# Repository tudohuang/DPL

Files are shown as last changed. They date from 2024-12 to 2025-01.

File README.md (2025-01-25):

# TISF 4th Prize!!!!!!

[URL](https://www.z-gtech.com.tw/TISF2025/100040.html)
# Digital Physics Laboratory Project Manual

## 1. Introduction
The Digital Physics Laboratory Project leverages millimeter-wave radar technology to enable precise, non-contact motion measurement for physics experiments. This manual serves as a comprehensive guide to understanding, replicating, and utilizing the system effectively, with a focus on making it accessible for educators and students.
This project is tailored to empower educators in creating engaging, hands-on experiences for students, bridging theoretical concepts with practical applications. Whether you are a teacher introducing basic mechanics or an advanced student exploring signal processing, this system provides a versatile platform to enhance learning.

## 2. System Overview

### Core Components

1. **Millimeter-Wave Radar**:
    - **Model**: RFbeam Microwave GmbH K-LC7
    - **Operating Frequency**: $f_t = 24GHz$
    - **Function**: Captures motion data and outputs analog signals, which are processed to derive velocity and displacement.
    - **Key Features**:
        - Compact design for easy integration.
        - High sensitivity for small motion detection.
    - **Applications**: Non-contact motion tracking, vibration analysis, and frequency measurement.

2. **Signal Conditioning Circuit**:
    - **Purpose**: Amplifies and filters radar output signals to ensure compatibility with the ADC in the ESP32 microcontroller.
    - **Design**:
        - Low-noise amplifier (LNA) using OPA4340 for signal amplification.
        - Band-pass filter to isolate desired frequency ranges.
    - **Software Tools**:
        - Designed using KiCad for schematics and PCB layout.
    - **Physical Details**:
        - Total PCB size: $\approx 500mm^2$
        - Compact design allows easy integration into enclosures.
    - **Applications**:
        - Noise reduction in signal acquisition.
        - Improved ADC accuracy and signal stability.

3. **ESP32 Microcontroller**:
    - **Purpose**: Converts conditioned analog signals to digital data and transmits them to a computer via a serial port for analysis.
    - **Key Features**:
        - 12-bit ADC resolution for high-accuracy digitization.
        - Real-time data processing capabilities.
    - **Software Support**:
        - Programmed using Arduino IDE for easy development and deployment.
    - **Connections**:
        - Analog input: Receives conditioned signals from the radar.
        - Serial output: Sends digital data to a connected PC or device.
    - **Applications**:
        - Real-time motion analysis.

4. **Python-Based Software**:
    - **Purpose**: Processes and visualizes the collected data from the ESP32.
    - **Key Features**:
        - **Signal Processing**:
            - High-pass filtering to remove low-frequency noise.
            - FFT (Fast Fourier Transform) for frequency domain analysis.
        - **Visualization**:
            - Time-domain plots for raw and filtered signals.
            - Frequency spectrum analysis for identifying dominant frequencies.
        - **Customization**:
            - Open-source Python scripts allow users to modify and expand functionality.
    - **User Interface**:
        - Provides a command-line interface (CLI) for loading and analyzing data.
        - Optional GUI for real-time visualization (developed using Tkinter).
    - **Applications**:
        - Understanding harmonic motion and resonance.

## 3. Hardware Guide

### Schematics
- The schematic (`design_project.pdf`) provides a detailed blueprint of the system. It includes:
  1. **Radar Module**: Interfaces with the 24 GHz radar.
  2. **Amplification Stage**: Features OPA4340 for low-noise signal conditioning.
  3. **Microcontroller Connections**: Configures ADC inputs and communication lines.
  4. **Power Management**: Converts 5V to 3.3V using AMS1117.

### PCB Design
- **Gerber Files**: Located in the `hardware/PCB/` folder, ready for PCB fabrication.
- **3D Model**: Available in `hardware/3D_model/` for visualization and enclosure design.
- **Assembly Notes**:
  1. Solder components carefully to avoid thermal damage.
  2. Use decoupling capacitors to stabilize power supply lines.

## 4. Firmware Guide

### Overview
The firmware is designed for the ESP32 microcontroller and performs:
1. **ADC Sampling**: Converts analog radar signals to digital data.
2. **Data Transmission**: Sends data wirelessly for analysis.

### File Structure
- `adc_sampling.cpp`: Initializes and manages ADC sampling.
- `esp32_config.cpp`: Sets up ESP32 peripherals.
- `main.ino`: Main entry point for the program.

### Deployment
1. Open the firmware folder in Arduino IDE.
2. Connect the ESP32 to your computer.
3. Select the appropriate board and port.
4. Upload the code to the ESP32.

---

## 5. Software Guide

### Python-Based Analysis
- The software is located in the `software/` folder.
- Required dependencies are listed in `requirements.txt`.
- Key scripts:
  1. `gui.py`: Provides a graphical interface for real-time analysis.
  2. `data_collector.py`: Handles data acquisition and preprocessing.

### Running the Software
1. Install dependencies:
   ```bash
   pip install -r requirements.txt
   ```
2. Execute the analysis script:
   ```bash
   python gui.py
   ```

---

## 6. Examples and Usage

### Example Data
- Sample datasets are provided in the `examples/` folder:
  - `spring_oscillation_20g.csv`: Data for 20g mass.
  - `spring_oscillation_40g.csv`: Data for 40g mass.

### Visualization
- Run the example analysis script:
  ```bash
  python analyze_example.py --input_file spring_oscillation_20g.csv
  ```
- Output includes:
  1. Frequency spectrum visualization.
  2. Filtered motion data.

### Teacher Notes
- Encourage students to hypothesize the effects of varying mass on oscillation frequency.
- Demonstrate how data filtering improves signal clarity and measurement accuracy.
- Use provided Python scripts as a stepping stone for students to develop their own data analysis tools.

---

## 7. Educational Applications

### Enhancing Physics Labs
This system introduces students to cutting-edge measurement techniques, bridging traditional physics experiments with modern technology:
- **Harmonic Motion Experiments**:
  - Measure oscillation frequencies of different masses.
  - Analyze how the spring constant and damping factors affect motion.
- **Waveform Analysis**:
  - Teach students about filtering and noise reduction.
  - Visualize motion data in real-time.

### Data Literacy
- **Data Collection**:
  - Show students how to collect accurate, repeatable measurements using radar and microcontrollers.
- **Data Analysis**:
  - Use Python scripts to process data, introducing students to concepts like FFT (Fast Fourier Transform) and time-domain analysis.

### Cross-Disciplinary Applications
This system provides opportunities for collaboration between physics, electronics, and computer science courses:
- **Physics**: Understanding motion and forces.
- **Electronics**: Building and testing circuits.
- **Programming**: Writing and modifying analysis scripts.

### Accessibility
- Open-source design ensures that schools with limited budgets can implement advanced measurement systems at a fraction of the cost of commercial solutions.
- Modular design allows educators to adapt the system for various experiments, from pendulum studies to resonance analysis.

### Inspiring Creativity
- Encourage students to explore beyond harmonic motion by experimenting with non-linear systems, compound pendulums, or even chaotic oscillators.
- Allow students to modify the firmware or analysis scripts to fit specific experimental needs.

---

## 8. Appendix

### Bill of Materials (BOM)
Refer to `hardware/bill_of_materials.csv` for a complete list of components, including:
- Resistors, capacitors, and ICs.
- Radar module and ESP32 board.

### FAQ
**Q**: What should I do if the radar output is noisy?
**A**: Ensure proper grounding and use shielded cables.

**Q**: How can I modify the filter parameters?
**A**: Edit the cutoff frequency and order in the firmware.

**Q**: Can this system be used for other types of motion analysis?
**A**: Yes, the modular design allows for various applications, including pendulums, resonance experiments, and fluid dynamics visualization.

### Example Output
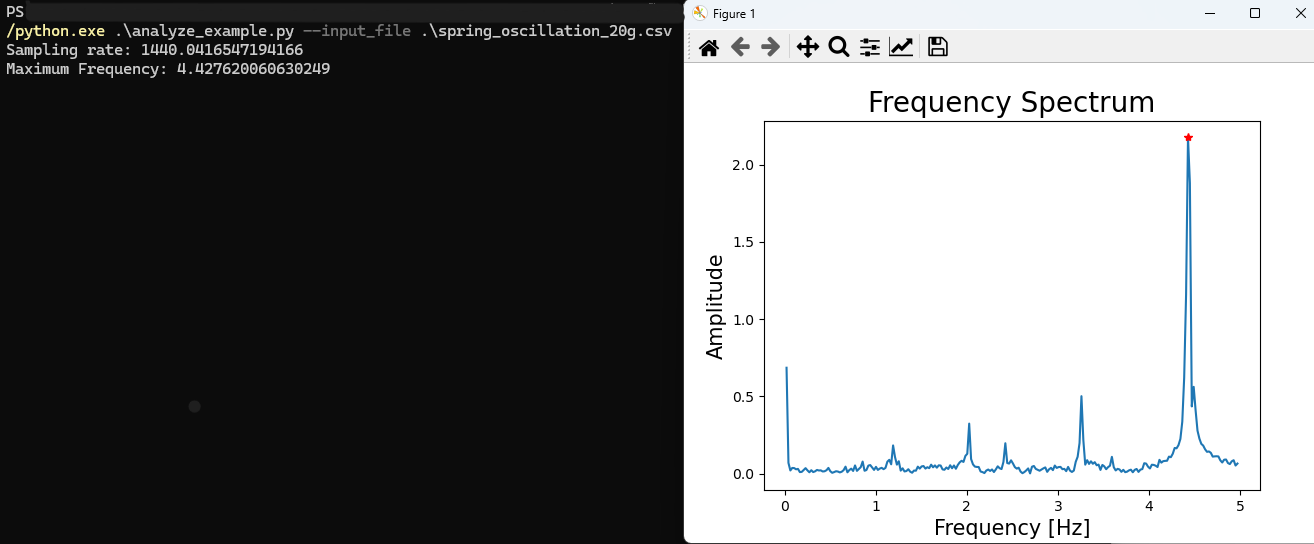
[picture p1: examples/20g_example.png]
Example Output

- Frequency spectrum of 20g mass oscillation.

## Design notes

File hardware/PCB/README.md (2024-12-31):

# PCB Design

This folder contains the Gerber files for manufacturing the PCB of the Digital Physics Laboratory project. These files are ready for direct submission to a PCB fabrication service.

## Files
- `design_project_top.gtl`: Top copper layer.
- `design_project_bottom.gbl`: Bottom copper layer.
- `design_project.gko`: PCB outline layer.
- `design_project_drills.xln`: Drill file for vias and holes.

## How to Use
1. Submit these files to a PCB manufacturer (e.g., JLCPCB, PCBWay).
2. Specify the board thickness and finish type as per your requirements.
3. Verify the design using a Gerber viewer before submission.

## Notes
- The PCB includes isolation between analog and digital sections to minimize noise.
- Ensure you procure components as per the Bill of Materials (BOM) for assembly.

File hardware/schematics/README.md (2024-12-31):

# Schematics

This folder contains the schematic for the Digital Physics Laboratory project in PDF format. The original editable schematic files are not included to ensure simplicity and compatibility.

## Files
- `design_project.pdf`: A complete schematic in PDF format for quick reference.

## How to Use
1. Open the `design_project.pdf` file in any PDF viewer.
2. Refer to the annotations in the schematic for component values and connections.

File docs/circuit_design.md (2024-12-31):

# Circuit Design

## Overview
The circuit design integrates a 24 GHz millimeter-wave radar module with a custom PCB, enabling precise and real-time motion measurement. The system is divided into three main parts:
1. **Analog Frontend**: Filters and amplifies radar signals.
2. **Microcontroller Unit (MCU)**: Converts analog signals to digital and transmits data.
3. **Power Supply**: Provides stable and regulated voltage for all components.

## Objectives
- Ensure low noise and high signal integrity.
- Optimize PCB layout for minimal interference.
- Enable compatibility with standard educational lab setups.

---

## System Architecture
The system architecture is divided into functional blocks:

### **1. Radar Module**
- **Component**: K-LC7 24 GHz Doppler Radar
- **Features**:
  - Transmits and receives radar signals.
  - Outputs raw analog signals proportional to motion.

### **2. Signal Conditioning**
- **Purpose**: Enhance radar output signals for ADC compatibility.
- **Components**:
  - **Operational Amplifier**: OPA4340 (Low noise, high precision), 4 OP included.
  - **Filters**:
    - **Bandpass Filter**: 4 Hz to 1 kHz to eliminate noise and unwanted frequencies.
    - **Low-pass Filter**: Attenuates high-frequency noise.
- **Implementation**:
  - Two-stage amplification with adjustable gain.

### **3. Microcontroller**
- **Component**: ESP32 Dev Module
- **Features**:
  - Built-in 12-bit ADC for analog-to-digital conversion.
  - Wi-Fi for wireless data transmission.
- **Firmware**:
  - Configures ADC for precise sampling.
  - Implements signal processing algorithms.

### **4. Power Supply**
- **Components**:
  - **Regulator**: AMS1117 (5V to 3.3V conversion).
  - **Decoupling Capacitors**: Reduces power supply noise.
- **Features**:
  - Ensures stable power for radar, MCU, and signal conditioning circuits.

---

## PCB Design
### **Software**
- Designed using **KiCad**:
  - Custom symbol and footprint libraries.
  - Layered PCB layout for signal integrity.

### **Layout**
- **Size**: 100 mm x 50 mm.
- **Layers**:
  - **Top Layer**: Analog and digital components.
  - **Bottom Layer**: Ground plane and power routing.
- **Highlights**:
  - Analog and digital sections are isolated to reduce interference.
  - Multiple vias for effective grounding.

---

## Schematic and PCB Files
- The complete schematic and PCB files are available in the `hardware/` folder:
  - `hardware/schematics/radar_module.sch`
  - `hardware/pcb/radar_module.kicad_pcb`

---

## Challenges and Solutions
### **Challenge**: High-frequency noise from radar output.
- **Solution**: Implemented multi-stage filtering and grounding techniques.

### **Challenge**: PCB space constraints.
- **Solution**: Used SMD components and optimized layout.

---

## Key Features
- Modular design allows easy upgrades.
- Low-cost components for educational accessibility.
- Open-source design to encourage replication and improvement.

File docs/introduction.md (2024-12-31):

# Introduction

## Abstract

Our study aims to design and apply a digital physics experimental system based on millimeter-wave radar, specifically for the precise quantification of spring harmonic motion. Traditional physics experiments are often limited by errors from manual measurements and visual observation, but this system uses a 24 GHz millimeter-wave radar combined with a custom-designed circuit board for real-time, non-contact motion measurement.

By designing the printed circuit board, writing firmware to convert analog signals into digital data, and using Python for data analysis, the system successfully measured the effects of different masses on the spring's oscillation frequency. The experimental results showed that after accounting for the spring's own mass, the root mean square error between the measured data and theoretical values decreased from 0.62 Hz to 0.35 Hz, demonstrating the system’s high accuracy. Additionally, the stability of the radar module in non-contact measurements highlights its potential applications.

This study successfully addressed measurement errors in traditional physics experiments, enabling precise observation of motion using millimeter-wave radar technology. Furthermore, the open-source design of this system will help promote its use in more school physics labs, providing students with advanced experimental tools and data analysis experience. The study showcases the potential of millimeter-wave radar technology in physics experiments and offers an efficient and low-cost solution for future teaching experiments.

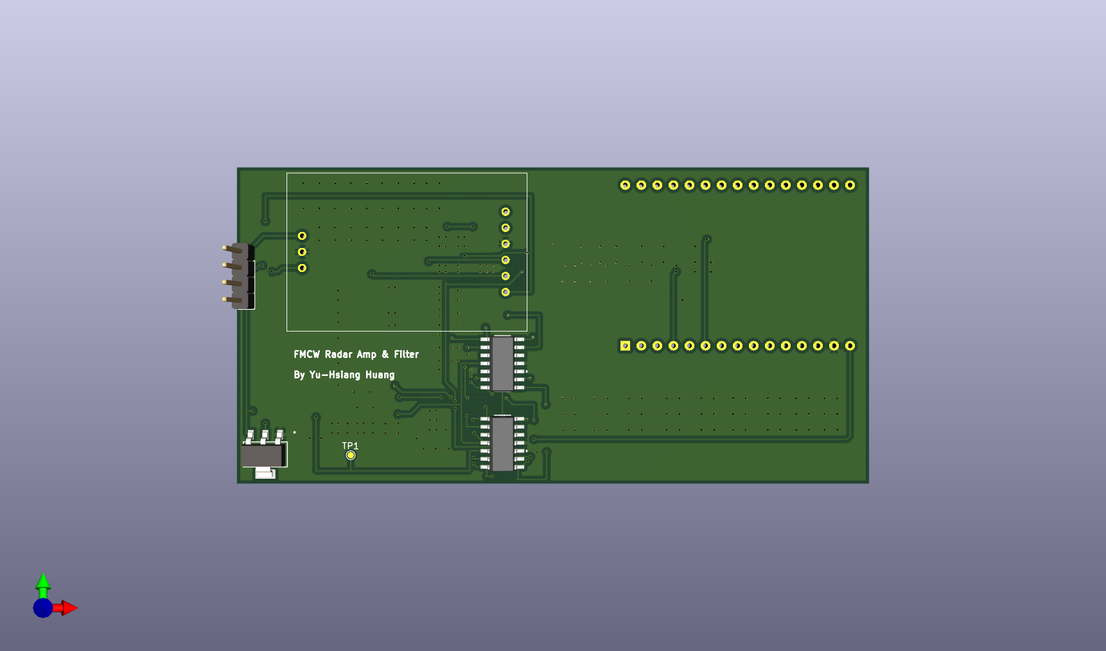
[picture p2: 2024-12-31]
hardware/3D_model/3d.png

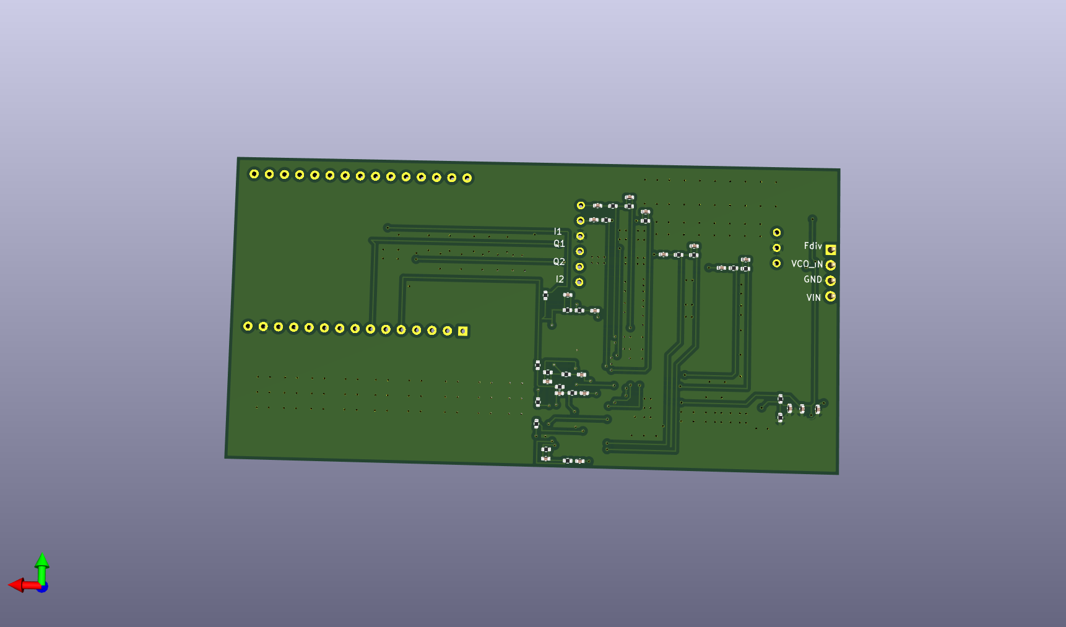
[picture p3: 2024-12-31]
hardware/3D_model/3d2.png

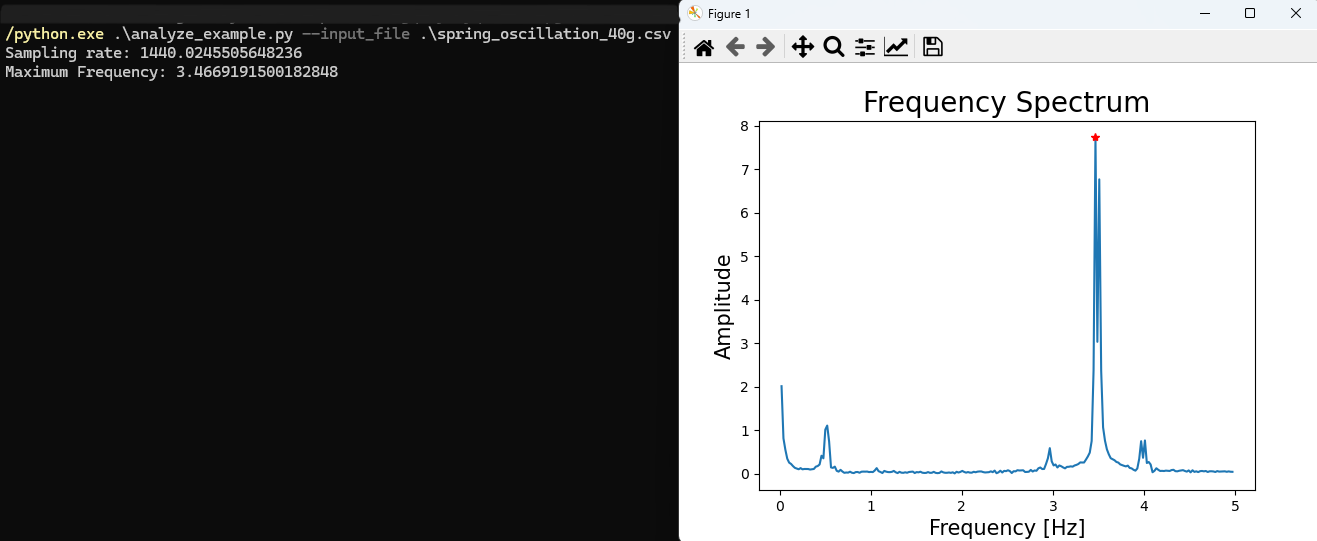
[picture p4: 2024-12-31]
examples/40g_example.png

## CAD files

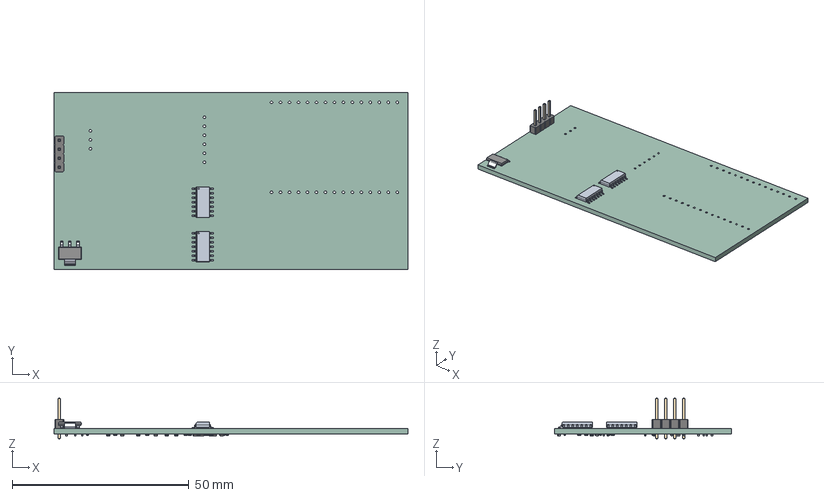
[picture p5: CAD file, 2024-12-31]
hardware/3D_model/pcb_design.step
100.0 x 50.0 x 11.5 mm
AMS1117-5.0
D14 x 2
PinHeader_1x04_P254mm_Vertical
C_0402_1005Metric x 19
R_0402_1005Metric x 22
Full_withESP_PCB

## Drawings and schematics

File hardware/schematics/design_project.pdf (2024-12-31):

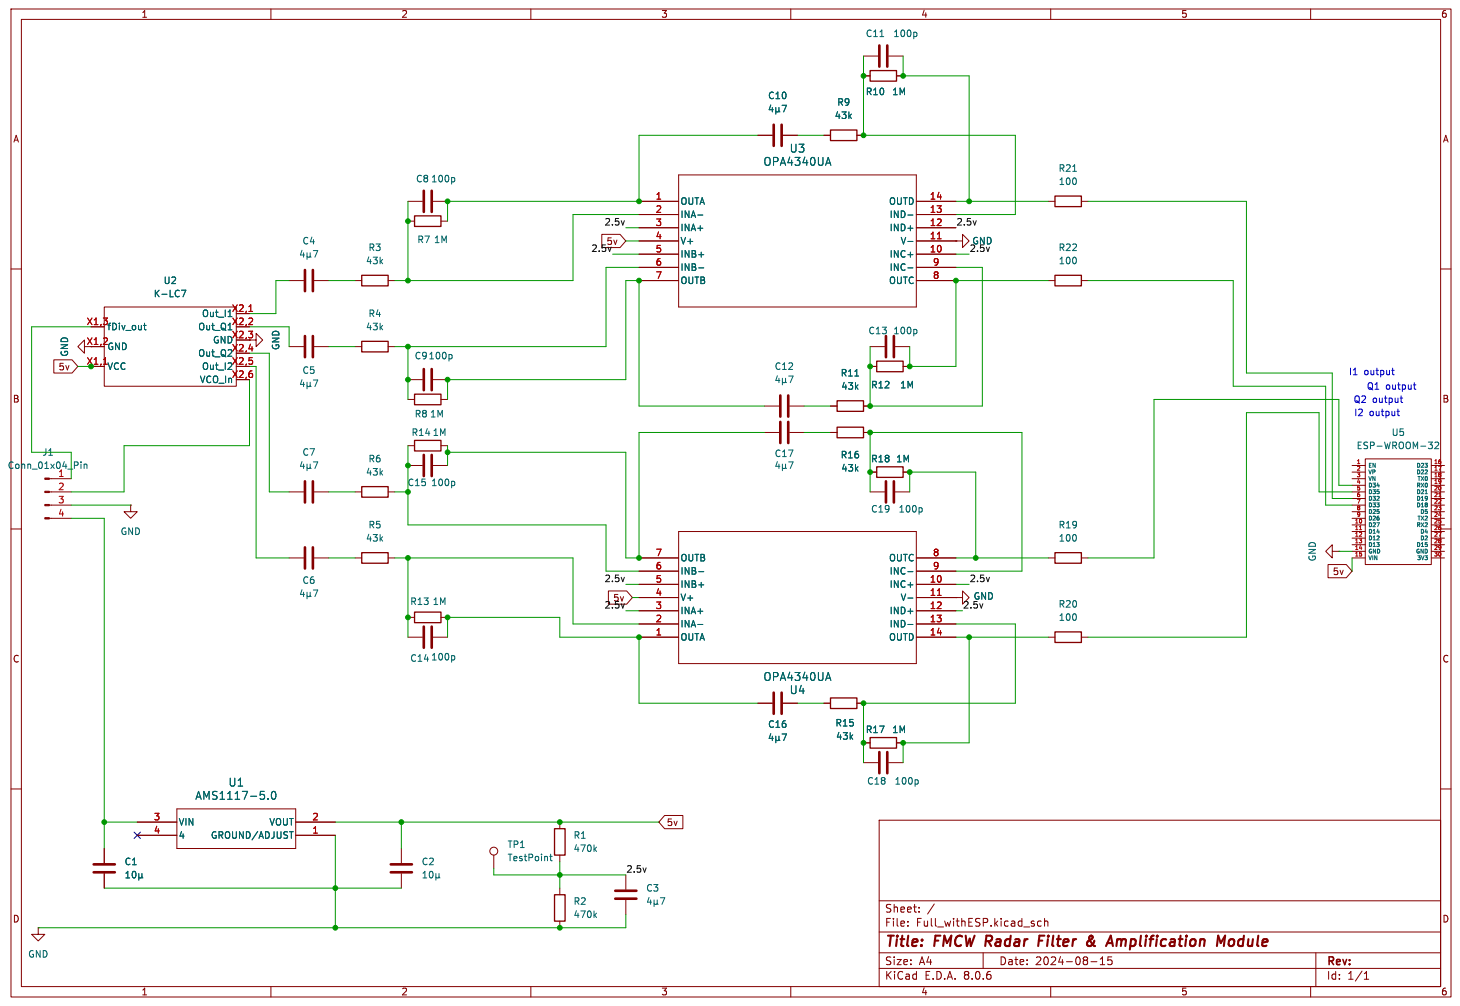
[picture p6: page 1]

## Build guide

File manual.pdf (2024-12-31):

# Digital Physics Laboratory

# Manual

Prepared by Yu-Hsiang Huang Date: 2024/12/31

# Contents

# Introduction

The Digital Physics Laboratory Project leverages millimeter-wave radar technology to enable precise, non-contact motion measurement for physics experiments. This manual serves as a comprehensive guide to understanding, replicating, and utilizing the system effectively, with a focus on making it accessible for educators and students. This project is tailored to empower educators in creating engaging, hands-on experiences for students, bridging theoretical concepts with practical applications. Whether you are a teacher introducing basic mechanics or an advanced student exploring signal processing, this system provides a versatile platform to enhance learning.

# System Overview

### 1. Millimeter-Wave Radar:

⚫ | Model: RFbeam Microwave GmbH K-LC7
⚫ | Operating Frequency: ft = 24GHz
⚫ | Function: Captures motion data and outputs analog signals,
which are processed to derive velocity and displacement.
⚫ | Key Features:
◼ | Compact design for easy integration.
◼ | High sensitivity for small motion detection.
⚫ | Applications: Non-contact motion tracking, vibration analysis,
and frequency measurement.

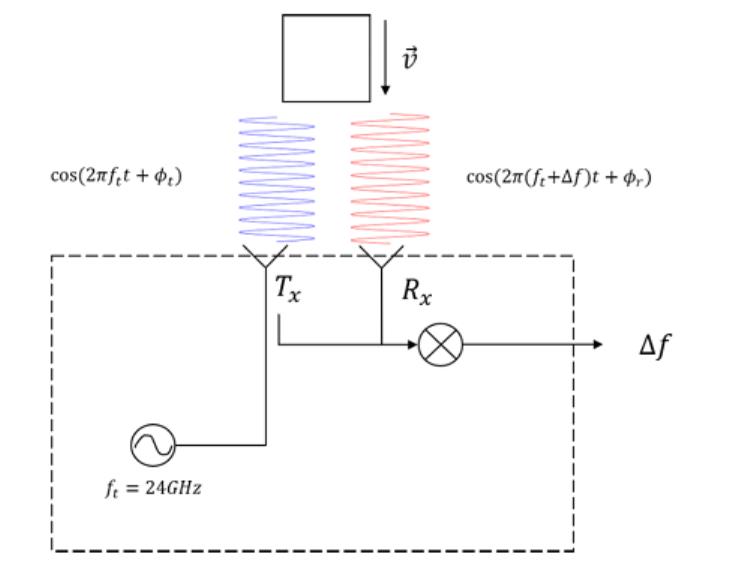
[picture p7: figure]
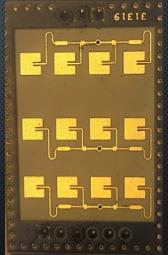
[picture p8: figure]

(Fig. 1: K-LC7 Module, Fig. 2: K-LC7 Schematic)

### 2. Signal Conditioning Circuit:

⚫ Purpose: Amplifies and filters radar output signals to ensure compatibility with the ADC in the ESP32 microcontroller.
⚫ | Design:
◼ | Band-pass filter to isolate desired frequency ranges.

⚫ Software Tools: Designed using KiCad for schematics and PCB layout.
⚫ | Physical Details:
◼ | Total PCB size:10cm × 5cm = 50cm²
◼ | Compact design allows easy integration into enclosures.
⚫ | Applications:
◼ | Noise reduction in signal acquisition.
◼ | Improved ADC accuracy and signal stability.

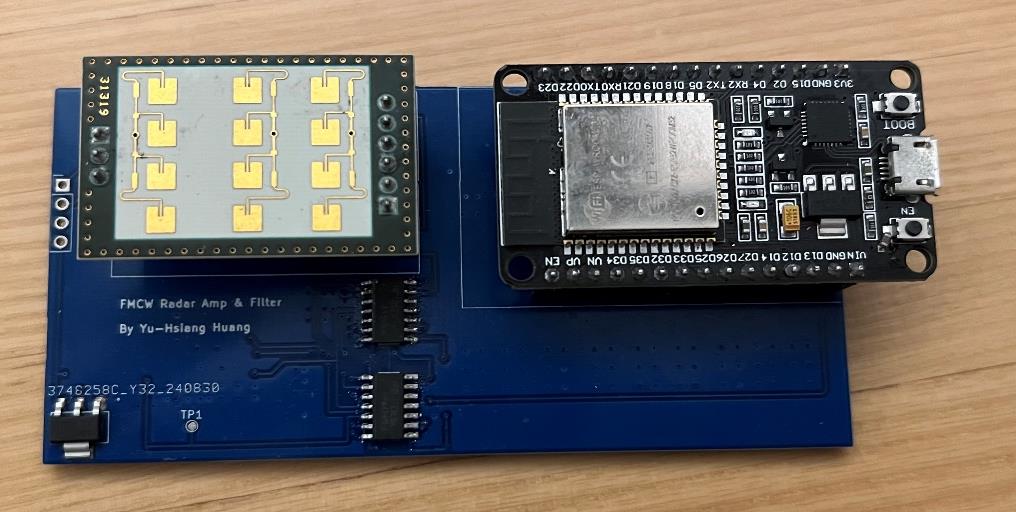
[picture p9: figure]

(Fig. 3: Signal Conditioning Circuit)

3.ESP32 Microcontroller:

⚫ Purpose: Converts conditioned analog signals to digital data and transmits them to a computer via a serial port for analysis.
⚫ Key Features:
12-bit ADC resolution for high-accuracy digitization.
Real-time data processing capabilities.
⚫ Software Support:
Programmed using Arduino IDE for easy development and deployment.
⚫ | Connections:
◼ | Analog input: Receives conditioned signals from the radar.
◼ | Serial output: Sends digital data to a connected PC or device.
⚫ | Applications: Real-time motion analysis.

### 4. Python-Based Software

⚫ Purpose: Processes and visualizes the collected data from the ESP32.
⚫ | Key Features:
◼ | Signal Processing:
◆ High-pass filtering to remove low-frequency noise. ◆ FFT (Fast Fourier Transform) for frequency domain analysis.
◼ Visualization:
◆ Time-domain plots for raw and filtered signals.
◆ Frequency spectrum analysis for identifying dominant frequencies.
◼ Customization:
◆ Open-source Python scripts allow users to modify and expand functionality.
⚫ | User Interface:
◼ | Provides a command-line interface (CLI) for loading and
analyzing data.
◼ Optional GUI for real-time visualization (developed using Tkinter).
⚫ | Applications:
◼ | Understanding harmonic motion and resonance

# Hardware Guide

Schematics

⚫ The schematic (design_project.pdf) provides a detailed blueprint of the system. It includes:
◼ | Radar Module: Interfaces with the 24 GHz radar.
◼ | Amplification Stage: Features OPA4340 for low-noise
signal conditioning.

◼ | Microcontroller Connections: Configures ADC inputs and
| communication lines.
◼ | Power Management: Converts 5V to 3.3V using AMS1117.

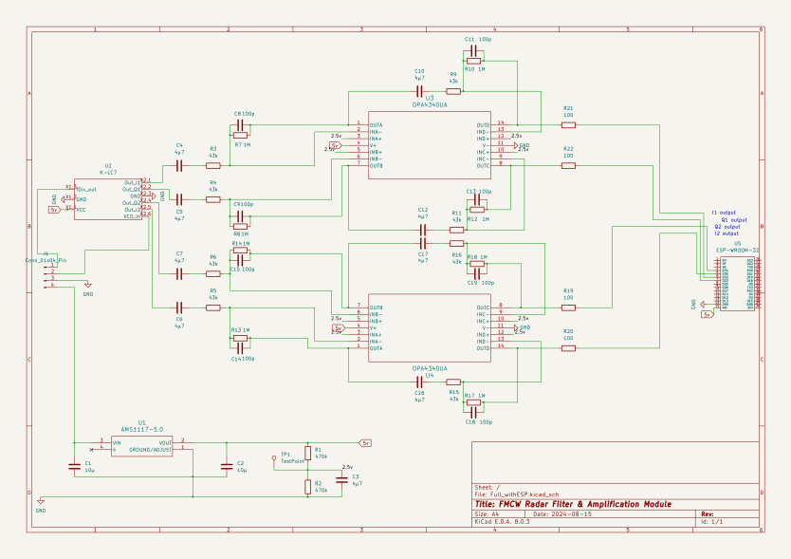
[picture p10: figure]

(Fig 4. Schematic)

PCB Design

⚫ Gerber Files: Located in the hardware/PCB/ folder, ready for PCB fabrication.
⚫ 3D Model: Available in hardware/3D_model/ for visualization and enclosure design.
⚫ | Assembly Notes:
◼ | Solder components carefully to avoid thermal damage.
◼ | Use decoupling capacitors to stabilize power supply lines

# Firmware Guide

Overview

The firmware is designed for the ESP32 microcontroller and performs:
1. ADC Sampling: Converts analog signals to digital data.
2. Data Transmission: Sends data wirelessly for analysis.

File Structure

⚫ | adc_sampling.cpp: Initializes and manages ADC sampling.
⚫ | esp32_config.cpp: Sets up ESP32 peripherals.

⚫ main.ino: Main entry point for the program.

Deployment

1. Open the firmware folder in Arduino IDE.
2. Connect the ESP32 to your computer.
3. Select the appropriate board and port.
4. Upload the code to the ESP32

# Software Guide

Python-Based Analysis

⚫ | The software is located in the software/ folder.
⚫ | Required dependencies are listed in requirements.txt.
⚫ | Key scripts:
◼ | gui.py: Provides a graphical interface for real-time/long-time
analysis.
◼ data_collector.py: Handles data acquisition and preprocessing.(CLI)

Running the Software

### 1. Install dependencies:

2.Execute the analysis script:

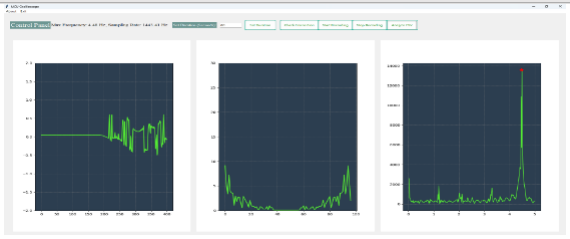
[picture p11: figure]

(Fig. 5: GUI demo)

pip install -r requirements.txt

python gui.py

# Examples and Usage

Example Data

⚫ Sample datasets are provided in the examples/ folder:
◼ | spring_oscillation_20g.csv: Data for 20g mass.
◼ | spring_oscillation_40g.csv: Data for 40g mass.

Visualization

⚫ Run the example analysis script:

⚫ Output:


(Fig. 6: Example output of 20g.csv)


(Fig. 7: Example output of 40g.csv) python analyze_example.py --input_file 20g.csv

# Educational Applications

Enhancing Physics Labs

This system introduces students to cutting-edge measurement techniques, bridging traditional physics experiments with modern technology:

⚫ Harmonic Motion Experiments:

◼ | Measure oscillation frequencies of different masses.
◼ | Analyze how the spring constant and damping factors affect
motion.

⚫ Waveform Analysis:

◼ | Teach students about filtering and noise reduction.
◼ | Visualize motion data in real-time.

Data Literacy

⚫ Data Collection:
◼ Show students how to collect accurate, repeatable measurements using radar and microcontrollers.
⚫ | Data Analysis:
◼ | Use Python scripts to process data, introducing students to
concepts like FFT (Fast Fourier Transform) and time-domain analysis.
Cross-Disciplinary Applications
This system provides opportunities for collaboration between physics, electronics, computer science, and math courses:
⚫ | Physics:
◼ | Harmonic Motion: Analyze oscillations.
◼ | Wave Phenomena:Study Doppler effect, and millimeter
waves.
⚫ | Electronics
◼ | Design, assemble, and test amplification and filtering
circuits for radar signals.
◼ | Use KiCad to create and optimize compact PCB layouts.
◼ | Write firmware for the ESP32 to perform ADC sampling and
serial communication.

⚫ | Computer Science:
◼ | Write and modify Python scripts to filter, analyze, and
visualize data in real-time.
⚫ | Math:
◼ | Apply FFT to transform motion data from the time domain
to the frequency domain.
◼ Calculate mean, variance, and standard deviation to evaluate experimental accuracy.
Accessibility
⚫ Open-source design ensures that schools with limited budgets can implement advanced measurementsystems at a fraction of the cost of commercial solutions.
⚫ The modular design allows educators to adapt the system to a variety of experiments, from oscillation studies to signal analysis.

# Appendix

Bill of Materials (BOM)
Refer to hardware/bill_of_materials.csv for a complete list of components, including:
⚫ | Resistors, capacitors, and ICs.
⚫ | Radar module and ESP32 board.

Price estimate per system

Name | Footprint | Amount | Price(total, USD)
AMS1117 | SOT223 | 1 | 0.5
OPA4340 | D14 | 2 | 2.40
PinHeader | Conn_01x04_Pin | 1 | 0.10
Capacitor | 0402 | 19 | 0.38
Resistor | 0402 | 22 | 0.67
ESP32 | ESP32-dev | 1 | 9.14
K-LC7 | K-LC7 | 1 | 57.28

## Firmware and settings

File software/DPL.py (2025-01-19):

import sys
import threading
import csv
import uuid
import numpy as np
from scipy.signal import butter, sosfilt, lfilter, firwin, savgol_filter
from PySide6.QtWidgets import (
    QApplication, QMainWindow, QStatusBar, QLabel, QMessageBox,
    QPushButton, QVBoxLayout, QWidget, QLineEdit, QFileDialog, QFrame, QHBoxLayout, QMenuBar,QTableWidget, QTableWidgetItem,QTabWidget,QSlider,QSizePolicy
)
from PySide6.QtCore import Qt
from PySide6.QtGui import QIcon
from math import sqrt, pi
from PySide6.QtCore import QTimer
from matplotlib.figure import Figure
from matplotlib.backends.backend_qt5agg import FigureCanvasQTAgg as FigureCanvas
import serial.tools.list_ports
from collections import deque
import time
import threading
from math import sqrt, pi

from scipy.signal import butter, filtfilt, sosfilt

def design_butterworth_filter(lowcut, highcut, fs, order=4):
    """
    Design a Butterworth bandpass filter.
    
    Parameters:
    - lowcut: Lower cutoff frequency (Hz).
    - highcut: Upper cutoff frequency (Hz).
    - fs: Sampling frequency (Hz).
    - order: Filter order (default: 4).
    
    Returns:
    - b, a: Filter coefficients.
    """
    nyquist = 0.5 * fs
    low = lowcut / nyquist
    high = highcut / nyquist
    sos = butter(order, [low, high], btype='band', output='sos')
    return sos






class OscilloscopeApp(QMainWindow):
    def __init__(self):
        super().__init__()
        self.setWindowTitle("MCU Oscilloscope - PySide6 Version")
        self.resize(800, 600)

        # Parameters
        self.recording = False
        self.recording_duration = 60
        self.serial_port = None
        self.sampling_rate = 1000
        self.fir_coeff = firwin(100, [0.03, 0.8], pass_zero=False)
        self.voltage_data = deque(maxlen=5000)  # 用於即時繪圖的 FIFO 緩存
        self.time_data = deque(maxlen=5000)  # 用於即時繪圖的 FIFO 緩存
        self.data_all = deque(maxlen=500000)
        self.long_term_data = deque(maxlen=500000)  # 用於長期數據記錄
        self.stop_event = None
        self.sos = None
        self.vline_without_mass = None
        self.vline_with_mass = None
        self.sos_status = True
        
        # Initialize UI
        self.setup_ui()
        self.apply_styles()
        self.setWindowIcon(QIcon(r"G:\.shortcut-targets-by-id\1hTHRprGG3w8dNgqo-yMJyqIEezOBEpgf\108課綱學習歷程\DPL\software\logo.ico"))

    def setup_ui(self):
        # Main Window
        central_widget = QWidget()
        self.setCentralWidget(central_widget)
        main_layout = QHBoxLayout(central_widget) # Horizontal layout, divided into left control area and right chart area

        # Left control panel
        control_panel = QFrame()
        control_panel.setObjectName("controlPanel")
        control_panel_layout = QVBoxLayout(control_panel)  # 使用 VBoxLayout 排列元件
        control_panel_layout.setSpacing(15)  # 設定元件之間的間距
        main_layout.addWidget(control_panel, 2)  # 將控制面板加入主佈局





        self.status_bar = QStatusBar()
        self.setStatusBar(self.status_bar)

        # Example: Setting the initial status message
        self.status_bar.showMessage("Ready")
        
        
        # Right chart area
        plots_frame = QFrame()
        plots_frame.setObjectName("plotsFrame")
        plots_layout = QVBoxLayout(plots_frame)
        main_layout.addWidget(plots_frame, 5) # The right chart area occupies 70%

        # Control area title
        control_title = QLabel("Build and discover!", self)
        control_title.setObjectName("controlTitle")
        control_panel_layout.addWidget(control_title, alignment=Qt.AlignCenter)


        self.labelsl = QLabel("Current Value: 20", self)
        self.labelsl.setStyleSheet("""
            QLabel {
                font-weight: bold;            /* 字體加粗 */
                color: aqua;                  /* 字體顏色 */
                border: 2px solid #4CAF50;    /* 邊框顏色與粗細 */
                border-radius: 8px;           /* 邊框圓角 */
                padding: 3px;                 /* 內距 */
                text-align: center;           /* 文字置中 */
                background-color: #1E1E1E;    /* 背景顏色 */
            }
        """)
        self.labelsl.setFixedHeight(30)  # 設定固定高度
        self.labelsl.setSizePolicy(QSizePolicy.Expanding, QSizePolicy.Fixed)  # 水平擴展，固定高度
        control_panel_layout.addWidget(self.labelsl)

        self.button = QPushButton("Filter OFF", self)
        self.button.setStyleSheet("background-color: lightgray; font-size: 18px;")
        control_panel_layout.addWidget(self.button)

        # 初始狀態
        self.is_on = False

        # 連接按鈕點擊事件
        self.button.clicked.connect(self.toggle)


        # 滑桿
        self.slider = QSlider(Qt.Horizontal, self)
        self.slider.setRange(20, 200)  # 設定範圍
        self.slider.setSingleStep(20)  # 設定步進值
        self.slider.setTickInterval(20)  # 設定刻度間隔
        self.slider.setTickPosition(QSlider.TicksBelow)  # 設定刻度位置
        self.slider.setValue(20)  # 設定初始值
        self.slider.setFixedHeight(20)  # 限制滑桿高度
        control_panel_layout.addWidget(self.slider)  # 將滑桿加入控制面板

        self.slider.valueChanged.connect(self.update_label)



        # Set the control area buttons and input box
        duration_layout = QHBoxLayout()
        duration_label = QLabel("Recording time (seconds):")
        duration_label.setObjectName("durationLabel")
        self.duration_input = QLineEdit("60")
        self.duration_input.setPlaceholderText("Enter seconds")
        duration_layout.addWidget(duration_label)
        duration_layout.addWidget(self.duration_input)
        control_panel_layout.addLayout(duration_layout)

        set_duration_btn = QPushButton("Set time")
        set_duration_btn.clicked.connect(self.set_duration)
        control_panel_layout.addWidget(set_duration_btn)

        check_connection_btn = QPushButton("Check connection")
        check_connection_btn.clicked.connect(self.check_connection)
        control_panel_layout.addWidget(check_connection_btn)

        start_recording_btn = QPushButton("Start recording")
        start_recording_btn.clicked.connect(self.start_recording)
        control_panel_layout.addWidget(start_recording_btn)

        analyze_csv_btn = QPushButton("Analyze CSV")
        analyze_csv_btn.clicked.connect(self.analyze_csv)
        control_panel_layout.addWidget(analyze_csv_btn)

        # Chart area
        voltage_label = QLabel("Voltage")
        voltage_label.setAlignment(Qt.AlignCenter)
        voltage_label.setObjectName("plotLabel")
        plots_layout.addWidget(voltage_label)
        self.voltage_canvas = self.create_plot("Voltage", "Time (s)", "Voltage (V)")
        plots_layout.addWidget(self.voltage_canvas)

        spectrum_label = QLabel("Spectrum")
        spectrum_label.setAlignment(Qt.AlignCenter)
        spectrum_label.setObjectName("plotLabel")
        plots_layout.addWidget(spectrum_label)
        self.spectrum_canvas = self.create_plot("Spectrum", "Frequency (Hz)", "Amplitude")
        plots_layout.addWidget(self.spectrum_canvas)
        plots_layout.setContentsMargins(10, 10, 10, 10)  # 設定外邊距（上、右、下、左）

        #analysis_label = QLabel("Analysis")
        #analysis_label.setAlignment(Qt.AlignCenter)
        #analysis_label.setObjectName("plotLabel")
        #plots_layout.addWidget(analysis_label)
        #self.analysis_canvas = self.create_plot("Analysis", "Frequency (Hz)", "Amplitude")
        #plots_layout.addWidget(self.analysis_canvas)


    def apply_styles(self):
        self.setStyleSheet("""
            QMainWindow {
                background-color: #1d1f27;
                color: #ffffff;
                font-family: 'Segoe UI', Arial, sans-serif;
            }
            #controlPanel {
                background-color: #2a2e38;
                border-radius: 12px;
                padding: 20px;
                margin: 10px;
            }
            #controlTitle {
                font-size: 24px;
                font-weight: bold;
                color: #61dafb;
                margin-bottom: 10px;
            }
            QLabel {
                font-size: 14px;
                color: #c3c3c3;
            }
            #durationInput {
                background-color: #3a3f4b;
                color: #ffffff;
                border: 2px solid #61dafb;
                border-radius: 8px;
                padding: 6px 10px;
                font-size: 14px;
            }
            QPushButton {
                background-color: #61dafb;
                color: #282c34;
                border: none;
                border-radius: 10px;
                padding: 12px 24px;
                font-size: 14px;
                font-weight: bold;
            }
            QPushButton:hover {
                background-color: #52bfe0;
            }
            QPushButton:pressed {
                background-color: #4eaecb;
            }
            #plotsFrame {
                background-color: #1e2029;
                border-radius: 12px;
                padding: 15px;
                margin: 10px;
            }
            QLabel#plotLabel {
                font-size: 18px;
                font-weight: bold;
                color: #61dafb;
                margin-bottom: 5px;
            }
                QStatusBar {
        background-color: #1d1f27;
        color: #61dafb;
        font-size: 14px;
        font-weight: bold;
    }
                        #controlTitle {
                            font-weight: bold;
                            color: #61dafb;

                        }

        """)




    def create_plot(self, title, xlabel, ylabel):
        fig = Figure(figsize=(8, 4), dpi=120, facecolor="#1d1f27")
        ax = fig.add_subplot(111)
        ax.set_xlabel(xlabel, fontsize=12, color='#ffffff')
        ax.set_ylabel(ylabel, fontsize=12, color='#ffffff')
        ax.tick_params(axis='x', colors='#c3c3c3')
        ax.tick_params(axis='y', colors='#c3c3c3')
        ax.grid(color='#444', linestyle='--', linewidth=0.5)
        ax.set_facecolor('#2a2e38')
        canvas = FigureCanvas(fig)
        canvas.ax = ax
        return canvas
    def update_voltage_plot(self):
        """更新電壓圖表。"""

        #filtered_data = lfilter(self.fir_coeff, 1.0, np.array(self.voltage_data))
        #filtered_data = savgol_filter(self.voltage_data, window_length=51, polyorder=3)
        filtered_data = self.voltage_data

        self.voltage_canvas.ax.clear()
        self.voltage_canvas.ax.plot( filtered_data, color='#55eb34', linewidth=2.0)
        #self.voltage_canvas.ax.set_xlabel("Time (s)", fontsize=12, color='white')
        self.voltage_canvas.ax.set_ylabel("Voltage (V)", fontsize=12, color='white')
        self.voltage_canvas.ax.set_ylim(-0.5, 2)
        self.voltage_canvas.ax.set_facecolor('#2c3e50')
        self.voltage_canvas.ax.grid(color='gray', linestyle='--', linewidth=0.5)
        self.voltage_canvas.draw()
    def update_spectrum_plot(self):
        """更新頻譜圖表。"""
        freq_points = int(self.sampling_rate * 20)
        if len(self.data_all) < freq_points: return 1
        freq_data = list(self.data_all)[-freq_points:]
        if self.is_on:
            freq_data = sosfilt(self.sos, freq_data)
        #freq_data = sosfilt(self.sos, freq_data)
        spectrum_data = np.abs(np.fft.fft(np.array(freq_data)))

        deltaf = self.sampling_rate/len(spectrum_data)
        data_points = int(5 // deltaf)

        spectrumX = np.arange(data_points)*deltaf

        XX = spectrumX[3:data_points]
        YY = spectrum_data[3:data_points]

        f,f_cal,fixed_value = self.update_label(self.slider.value())
        self.sos = design_butterworth_filter(max(round(f_cal)-1,1.5), round(f_cal)+1, self.sampling_rate, 10)
        maxi = np.argmax(YY)

        self.spectrum_canvas.ax.clear()
        self.spectrum_canvas.ax.plot(spectrumX[3:data_points], spectrum_data[3:data_points], color='#55eb34', linewidth=2.0)
        self.spectrum_canvas.ax.plot(XX[maxi], YY[maxi], 'r*')
        #self.spectrum_canvas.ax.set_xlabel("Frequency (Hz)", fontsize=12, color='white')
        self.spectrum_canvas.ax.set_ylabel("Amplitude", fontsize=12, color='white')
        self.spectrum_canvas.ax.set_xlim(0, 5.5)
        self.spectrum_canvas.ax.set_ylim(0, spectrum_data[3:data_points].max()*1.2)
        self.spectrum_canvas.ax.set_facecolor('#2c3e50')
        self.spectrum_canvas.ax.grid(color='gray', linestyle='--', linewidth=0.5)
        self.spectrum_canvas.ax.axvline(x=f, color='r', linestyle='--')#, label=f'w/o mass = {f:.2f} Hz')
        self.spectrum_canvas.ax.axvline(x=f_cal, color='y', linestyle='--')#, label=f'w/ mass = {f_cal:.2f} Hz')
        self.spectrum_canvas.draw()

        self.update_status(f"Max freq: {XX[maxi] :.2f} Hz")


    def read_and_plot_data(self, stop_event):
        """從 ESP32 獲取數據並即時繪圖。"""
        partial_line = ''
        port = self.detect_esp32_port()
        if port is None:
            self.update_status("Port not found!")
            return

        ser = serial.Serial(port, 115200)
        ser.flush()
        start_time = time.time()

        while not stop_event.is_set():
            if ser.in_waiting:
                # 獲取數據並分行處理
                data = partial_line + ser.read(ser.in_waiting).decode('utf-8', errors='ignore')
                lines = data.split('\n')
                partial_line = lines[-1]

                for line in lines[:-1]:
                    try:
                        voltage = float(line)
                        timestamp = time.time() - start_time
                        self.voltage_data.append(voltage-2.2)  # 更新即時繪圖緩存
                        self.data_all.append(voltage-2.2)
                        self.time_data.append(timestamp)

                        if self.recording:
                            self.long_term_data.append((timestamp, voltage))  # 若正在記錄，保存數據

                    except ValueError:
                        continue


    def show_about(self):
        self.status_bar.showMessage("This GUI app is a oscilloscope for MCU.")

    def set_duration(self):
        try:
            duration = int(self.duration_input.text())
            self.status_bar.showMessage(f"Recording time set to {duration} seconds.")
        except ValueError:
            self.status_bar.showMessage("Invalid duration input.")


    def update_status(self, new_status):
        self.status_bar.setStyleSheet("color: #61dafb;")
        self.status_bar.showMessage(new_status)

    def detect_esp32_port(self):
        ports = list(serial.tools.list_ports.comports())
        for port in ports:
            if any(keyword in port.description for keyword in ["USB-SERIAL", "CP210", "Arduino"]):
                return port.device
        return None

    def check_connection(self):
        port = self.detect_esp32_port()
        if port is None:
            self.update_status("ESP32 not found!")
            QMessageBox.critical(self, "Connection Error", "ESP32 not found. Please connect the device and try again.")
        else:
            self.update_status(f"ESP32 connected on {port}")
            self.stop_event = threading.Event()
            threading.Thread(target=self.read_and_plot_data, args=(self.stop_event,), daemon=True).start()

            for ii in range(5):
                time.sleep(1)
                self.update_status(f"Calibrating.....{ii + 1} s")
                
            

            samples = len(self.voltage_data)
            deltat = self.time_data[-1] - self.time_data[0]

            self.sampling_rate = int(samples/deltat)
            
            self.update_status(f'Sampling frequency: {self.sampling_rate} Hz')

            self.sos = design_butterworth_filter(2, 4, self.sampling_rate, 10)


            # QTimer Setup
            self.timer1 = QTimer(self)  # Create QTimer instance
            self.timer1.timeout.connect(self.update_voltage_plot)  # Connect timeout signal to the function
            self.timer1.start(10)  # Set interval to 100 ms

            self.timer2 = QTimer(self)  # Create QTimer instance
            self.timer2.timeout.connect(self.update_spectrum_plot)  # Connect timeout signal to the function
            self.timer2.start(200)  # Set interval to 100 ms

            self.update_status(f'Displaying ...')

    
    def toggle(self):
        self.is_on = not self.is_on
        self.sos_status = not self.sos_status

        # 更新按鈕文字與顏色
        if self.is_on:
            self.button.setText("Filter ON")
            self.button.setStyleSheet("background-color: aqua; font-size: 18px; color: white;")
        else:
            self.button.setText("Filter OFF")
            self.button.setStyleSheet("background-color: lightgray; font-size: 18px; color: black;")

    def start_recording(self):
        try:
            self.recording_duration = int(self.duration_input.text())
            self.long_term_data.clear()
            self.recording = True
            self.update_status(f"Recording started for {self.recording_duration} seconds.")
            QTimer.singleShot(self.recording_duration * 1000, self.stop_recording)
        except ValueError:
            QMessageBox.critical(self, "Invalid Input", "Please enter a valid integer for recording time.")

    def stop_recording(self):
        self.recording = False
        if self.stop_event:
            self.stop_event.set()
        self.update_status("Recording stopped.")
        self.save_data_to_csv()


    def save_data_to_csv(self):
        file_name, _ = QFileDialog.getSaveFileName(self, "Save Recording", "", "CSV Files (*.csv)")
        if file_name:
            with open(file_name, 'w', newline='') as file:
                writer = csv.writer(file)
                writer.writerow(["Timestamp (s)", "Voltage (V)"])
                writer.writerows(self.long_term_data)
            self.update_status(f"Data saved to {file_name}.")

    def analyze_csv(self):
        file_path, _ = QFileDialog.getOpenFileName(self, "Open CSV", "", "CSV Files (*.csv)")
        if not file_path:
            return

        try:

            self.timer1.stop()
            self.timer2.stop()

            # Load data from CSV
            data = np.loadtxt(file_path, delimiter=',', skiprows=1)
            time_data = data[:, 0]
            signal_data = data[:, 1]
            sampling_rate = data.shape[0] / (time_data[-1] - time_data[0])
            print(f'Sampling rate: {sampling_rate:.2f} Hz')

            # High-pass filter
            cutoff_frequency = 0.1
            order = 8
            sos = butter(order, cutoff_frequency, btype='high', fs=sampling_rate, output='sos')
            filtered_signal = sosfilt(sos, signal_data)

            # Smooth the signal
            window_length = 100
            b = np.ones(window_length) / window_length
            smoothed_signal = lfilter(b, 1, np.abs(filtered_signal))

            # FFT analysis
            spectrum = np.abs(np.fft.fft(signal_data))
            freqs = np.fft.fftfreq(len(signal_data), d=1/sampling_rate)

            # Find max frequency
            max_index = np.argmax(spectrum[1:int(4.5 / (sampling_rate / spectrum.size))]) + 1
            max_frequency = max_index * sampling_rate / spectrum.size
            max_amplitude = spectrum[max_index]
            print(f'Max Frequency: {max_frequency:.2f} Hz')


            # Update the analysis plot
            self.spectrum_canvas.ax.clear()
            #self.spectrum_canvas.ax.set_xlabel("Frequency [Hz]")
            self.spectrum_canvas.ax.set_ylabel("Amplitude")
            self.spectrum_canvas.ax.grid(color='gray', linestyle='--', linewidth=0.5)
            self.spectrum_canvas.ax.plot(freqs[1:int(5 / (sampling_rate / spectrum.size))],
                                        spectrum[1:int(5 / (sampling_rate / spectrum.size))], color='#55eb34')
            self.spectrum_canvas.ax.plot(max_frequency, max_amplitude, 'r*', markersize=10)

            self.spectrum_canvas.draw()

            # Update the status
            self.update_status(f"Max Frequency: {max_frequency:.2f} Hz, Sampling Rate: {sampling_rate:.2f} Hz")

        except Exception as e:
            QMessageBox.critical(self, "Error", f"Failed to analyze CSV file: {e}")

    def theoretical_frequency(self,m,m0,k):
        f = 1/(2*pi)*sqrt(k/m)
        f_cal = 1/(2*pi)*sqrt(k/(m+m0/3))
        return f,f_cal
        
    
    def update_label(self, value):
        """更新標籤的值並更新鉛直線"""
        fixed_value = round(value / 20) * 20
        self.slider.blockSignals(True)  # 阻止遞迴觸發
        self.slider.setValue(fixed_value)
        self.slider.blockSignals(False)  # 恢復訊號觸發
        #self.labelsl.setText(f"Mass：{fixed_value}")  # 更新標籤

        # 計算新頻率值
        f, f_cal = self.theoretical_frequency(fixed_value / 1000, 0.028, 26.07)
        self.labelsl.setText(f"Mass: {fixed_value} g, w/o mass: {f:.2f} Hz, w/ mass: {f_cal:.2f} Hz")

        return f,f_cal,fixed_value
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

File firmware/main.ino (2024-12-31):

#include <Arduino.h>
#include "adc_sampling.h"
#include "esp32_config.h"

// 常量設定
#define BUFFER_SIZE 1024               // 緩衝區大小
#define ADC1_I_CHANNEL ADC1_CHANNEL_5  // GPIO 34

// 緩衝區
int16_t i_buffer[BUFFER_SIZE];         // 原始數據緩衝區
float voltage_buffer[BUFFER_SIZE];    // 電壓緩衝區

void setup() {
  setupSerial(115200);          // 初始化串列埠
  setupADC(ADC1_I_CHANNEL);     // 初始化 ADC
  Serial.println("ADC initialized");
}

void loop() {
  static int index = 0;

  // 讀取 ADC 數據
  int raw = readADC(ADC1_I_CHANNEL);

  // 存入緩衝區並轉換為電壓值
  i_buffer[index] = raw;
  voltage_buffer[index] = (raw / 4095.0) * 3.3;

  // 輸出電壓值
  Serial.println(voltage_buffer[index], 4);  // 保留 4 位小數

  // 更新緩衝區索引
  index++;
  if (index >= BUFFER_SIZE) {
    index = 0;  // 緩衝區滿時重置索引
  }
}
